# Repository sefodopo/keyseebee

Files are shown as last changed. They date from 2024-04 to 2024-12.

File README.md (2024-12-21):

# KeySeeBee (modified from [TeXitoi/keyseebee](https://github.com/TeXitoi/keyseebee))

KeySeeBee

KeySeeBee is a split ergo keyboard. It is only 2 PCB (so the name)
with (almost) only SMD components on it. It's no longer only a keyboard,
it now has keys, USB, rotary encoders, and OLEDs.

The old firmware at [Keyberon](https://github.com/TeXitoi/keyberon), a
pure rust firmware, has not been ported yet as I wanted more of the functionality
that QMK provides without having to code some of those advanced features.

QMK firmware for this version is located [here](https://github.com/sefodopo/qmk_firmware/tree/keyseebee).

## Features

 * 44 keys, using Cherry MX or Kailh choc switches, only 1U keycaps.
 * USB-C connector on the 2 sides.
 * TRRS cable for connecting the 2 halves (for power and UART communication between the 2 halves).
 * 2 STM32F072 MCU, with hardware USB DFU bootloader and crystal less USB;
 * Only onboard SMD components (except for the switches, TRRS
   connector, and optional components).
 * 2 SPI OLED 128x32 3.3V (optional not SMD)
 * 2 EC11 Rotary Encoder (optional not SMD)
 * [Plate files](cad/) (optional).

## Inspiration

 * [Plaid](https://github.com/hsgw/plaid) for "show the components"
 * [GergoPlex](https://www.gboards.ca/product/gergoplex) for "just a keyboard" and "only a PCB with SMD components"
 * [Lily58](https://github.com/kata0510/Lily58) for the thumb cluster
 * [Kyria](https://blog.splitkb.com/blog/introducing-the-kyria) for
   "don't be affraid of pinky stagger"
 * [keyseebee](https://github.com/TeXitoi/keyberon) for initial design without the OLEDs and Encoders and way too many diodes :)

## Gallery

### v0.1, build by TeXitoi

From above with one side upside down

Side view

### v0.1, build by TeXitoi, Gateron silent clear (MX footprint), 3D printed plate

From above

### v0.2, build by eropleco, with 1.2mm anodized aluminium plate

Left

Right

### v0.3, build by TeXitoi, Gateron silent clear, 3D printed fat plate

Side view

### v0.4, build by Sefodopo, Coming Sometime?

## Bill Of Materials

Price is for 5 keyboards including shipping.

|Item |Package|Qty|Remarks |Price |
|---|---|--:|---|-----:|
|[Left PCB](pcb/gerbers/) | |  1|Ordered at [JLCPCB](https://jlcpcb.com)| |
|[Right PCB](pcb/gerbers/) | |  1|Ordered at [JLCPCB](https://jlcpcb.com)|33.14€|
|[USB-C connector](https://www.aliexpress.com/item/33004501788.html) |16 pins|  2| | 1.44€|
|[PJ320A TRRS connector](https://www.aliexpress.com/item/4000661212458.html)| |  2| | 1.01€|
|[STM32F072CBT6 MCU](https://www.aliexpress.com/item/1005002841528809.html)|LQFP-48|  2|STM32F072C8T6 would also work | 9.65€|
|[XC6206P332MR regulator](https://www.aliexpress.com/item/33015891307.html)|SOT-23 |  2|Price is for 50 | 1.93€|
|[SMD switch](https://www.aliexpress.com/item/4000546059630.html) | 3×6mm |  4|Price is for 100 | 1.35€|
|[5.1kΩ resistor](https://www.aliexpress.com/item/32865947306.html) | 0805  |  6|Price is for 100 | |
|[1µF capacitor](https://www.aliexpress.com/item/32964553793.html) | 0805  |  4|Price is for 100 | |
|[100nF capacitor](https://www.aliexpress.com/item/32964553793.html) | 0805  | 10|Price is for 100 | 3.46€|
|[Bumpers](https://www.aliexpress.com/item/32289191938.html) | 5×2mm | 10|Price is for 100 | 1.75€|
|[Cherry MX compatible](https://www.aliexpress.com/item/32836368723.html) or [Kailh Choc](https://www.aliexpress.com/item/1005005883472162.html) switch|5 pins (PCB mount)|44| | |
|1U keycap compatible with the chosen switches | | 44| | |
|[TRRS cable](https://www.aliexpress.com/item/1005003677396291.html) |Jack 3.5mm| 1|4 contacts needed | |
|[USB-C cable](https://www.aliexpress.com/item/1005002811739151.html) | |  1|USB-2 is enough | |

About 60€ without switches, keycaps and cables for 5 keyboards
(12€/keyboard).

## Compiling and flashing

Follow the QMK guides using my branch of qmk_firmware (or copy my code, idk)... I might add more specific steps in the future.
## What's the layout

Yeah, I'm still figuring it out. I really prefer ZMK and if I can get ZMK working on this keyboard, I'll start using that instead
and update the layout here for what I like.

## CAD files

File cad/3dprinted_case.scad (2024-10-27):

use <functions.scad>

// Change to large number when pruducing end result
// 256 seems fine for production...
$fn = $preview ? 16 : 256;


// Screws and Encoders are different on each side
is_right = false;
// Select the part to show, b bottom, t top, p plate
part = "a";

// See functions.scad for more info
switch_hole = 14;
plate_thickness = 5;
switch_snapping = 1.5;
plate_case_tolerance = 0.03;
plate_inset = 1;
keycap_length = 18.3;
keycap_tolerance = 0.5;
// PCB is 4.3
screw_hole_diameter = 3; 
screw_depth = plate_thickness - switch_snapping-0.2;
chamfer_depth = 0.2;
rim_height = 6;
// Make sure to check dovetails when adjusting
case_width = 3;
case_pcb_tolerance = 0.3;
pcb_thickness = 1.6;
bottom_thickness = 2;
// Below the pcb, pcb+components on back (1.6+2ish)=4ish
case_separation = 4;
case_depth = case_separation+bottom_thickness;
// Depth of screw head for countersink I measured 1.2. Higher number to require shorter screws
screw_head = 3;
// 2.1 shrunk down to 2 and 2.3 was still just barely tight
screw_outer_diameter = 2.4;
// 4 shrunk too much for my wider head screws
screw_head_diameter = 4.5;
usb_thickness = 8;
corner_radius = 3;
bottom_case_tolerance = plate_case_tolerance;

tenting_angle = 25;

module everything() {
  if (part == "b") {
    bottom();
    tent();
  } else if (part == "t")
    rims();
  else if (part == "p")
    real_plate();
  else {
    tent();
    bottom();
    rims();
    real_plate();
  }
}

module tent() {
  angle = tenting_angle;
  outer_width = 136.165+2*(case_width+case_pcb_tolerance);
  right_offset = 85.835+case_width+case_pcb_tolerance;
  left_offset = 50.44+case_width+case_pcb_tolerance;
  start = plate_thickness+case_depth;
  cylen = outer_width * tan(angle)+0.02;
  cydia = 5;
  if (angle >= 5) translate([0,0,start-0.1-0.001]) difference() {
    linear_extrude(outer_width*tan(angle)+1) rim_outline();
    translate([-0.001,-0.001,-0.001+right_offset*tan(angle)+1]) rotate([0,angle,0]) linear_extrude(outer_width*tan(angle)+1+0.002) offset(delta=outer_width/cos(angle)-outer_width) rim_outline();
    if (outer_width*tan(angle)+1 > 10) {
      hyp = tan(angle)*outer_width-10;
      #translate([-left_offset-0.001,-75,10]) rotate([0,angle-90,0]) cube([hyp*cos(angle)+1.002,150,sin(angle)*hyp+1.001]);
    }
    translate([0,0,-0.001]) plate_screw_placement() {
      cylinder(h=1,d1=screw_head_diameter, d2=cydia);
      translate([0,0,1-0.001]) cylinder(h=cylen-1,d=cydia);
    }
  }
}

scale([is_right?-1:1,1,1]) everything();


// Top level modules
module real_plate() {
  difference() {
    linear_extrude(plate_thickness-0.48) difference() {
      offset(delta=plate_inset) plate_outline_interconnect();
      weird_rim_cutout();
    }
    translate([0,0,-0.001]) linear_extrude(plate_thickness+0.002) key_holes();
    translate([0,0,switch_snapping]) linear_extrude(plate_thickness+0.001) key_holes(15);
    translate([0,0,plate_thickness-screw_depth]) plate_screw_placement() {
      cylinder(h=screw_depth+0.001, d=screw_hole_diameter);
    };
    smd_holes();
    encoder_hole();
    usb_holes();
  }
}

module rims() {
  module case_rims() {
    difference() {
        fill() rim_placement();
        offset(delta=-case_width) fill() rim_placement();
      }
  }
  // We go from top to bottom which is actually bottom to top since the model is flipped :)
  difference() {
    union() {
      // top rounded part of case
      translate([0,0,-rim_height]) difference() {
        rd = 0.2;
        radius = case_width+case_pcb_tolerance-rd;
        minkowski() {
          linear_extrude(height=rim_height-radius+0.001) offset(delta=rd) pcb_outline();
          translate([0,0,radius]){
            difference() { // semisphere
              sphere(r=radius);
              translate([0,0,radius+0.001]) cube(radius*2+0.002, center=true);
            }
          }
        }
        translate([0,0,-0.001]) linear_extrude(height=rim_height+0.003)plate_outline();
      }

      // plate slice
      translate([0,0,-0.001]) linear_extrude(plate_thickness-0.4+0.002) {
        difference() {
          rim_placement(); 
          offset(delta=plate_inset+plate_case_tolerance) plate_outline_interconnect();
        }
        offset(delta=-2*plate_case_tolerance) weird_rim_cutout();
      }
      translate([0,0,plate_thickness-0.4-0.001]) linear_extrude(0.4+0.002) difference() {
        fill() rim_placement();
        plate_outline();
      }

      // pcb slice
      translate([0,0,plate_thickness-0.001]) linear_extrude(case_depth-bottom_thickness+0.002) difference() {
        rim_outline();
        offset(delta=-case_width) rim_outline();
      }

      // bottom cover slice
      translate([0,0,plate_thickness+case_depth-bottom_thickness-0.001]) linear_extrude(height=bottom_thickness+0.002) difference() {
        rim_outline();
        offset(r=-case_width/2) rim_outline();
      }
    }
    encoder_hole();
    smd_holes();
    translate([0,0,switch_snapping]) linear_extrude(plate_thickness+0.001) key_holes(15);
    translate([0,0,plate_thickness-screw_depth]) plate_screw_placement() {
      cylinder(h=screw_depth+0.002, d=screw_hole_diameter);
    };
    usb_holes();
    // trrs port
    translate([-46.863,19.652,plate_thickness-6]) linear_extrude(6) square([7,15], center=true);
    translate([-46.863,26,plate_thickness-2.5]) rotate(-90, [1,0,0]) linear_extrude(20) circle(d=8);
  }
}


module bottom() {
  start = plate_thickness+case_depth-bottom_thickness;
  end = plate_thickness+case_depth;
  difference() {
    union() {
      translate([0,0,start]) linear_extrude(bottom_thickness) 
        offset(r=-case_width/2) offset(delta=-bottom_case_tolerance) rim_outline();
      plate_screw_placement() {
        translate([0,0,plate_thickness+bottom_case_tolerance]) cylinder(h=2+0.001,d=4);
        translate([0,0,plate_thickness+bottom_case_tolerance+1.8-0.001]) cylinder(h=start-plate_thickness-bottom_case_tolerance+0.001, d1=4, d2=10);
      }
    }

    plate_screw_placement() {
      translate([0,0,start-case_separation-0.001]) cylinder(h=bottom_thickness+case_separation+0.002,d=screw_outer_diameter);
      translate([0,0,end-screw_head]) cylinder(h=1.5+0.001, d1=screw_outer_diameter, d2=screw_head_diameter);
      translate([0,0,end-screw_head+1.5-0.001]) cylinder(h=screw_head-1.5+0.002,d=screw_head_diameter);
    }
  }
}


// Top level 2d modules

// The outline of the plate where the rims should start
module plate_outline() {
  // My keycaps are 18.3mm^2
  offset(delta=keycap_tolerance) key_holes(keycap_length);
}

module weird_rim_cutout() {
  offset(delta=plate_case_tolerance) intersection() {
    rim_placement();
    translate([-10,-37.965]) square([40,20]);
  }
}

module plate_outline_interconnect() {
  plate_outline();

  // Add padding for the screw
  translate([-27,-49]) square([10,10]);

  // Dovetails
  d = keycap_length/2+keycap_tolerance+plate_inset;
  translate([76.2+d-0.001,-12.7]) rotate(-90) dovetail(w=20,h=0.3);
  translate([-19.05-d+0.001,0]) rotate(90) dovetail(w=17,h=1);
  translate([57.15-6,-29.21-d+0.001]) rotate(180) dovetail(w=8,h=2);
  translate([57.15+2,8.89+d-0.001]) dovetail(w=4,h=2);
  translate([-32.131,-45.72]) rotate(26.5) translate([0,-d+0.001]) rotate(180) dovetail(w=7,h=0.5);
  translate([19.05,21.59+d-0.001]) dovetail(h=0.01);
  translate([-2,19.05+d-0.001]) dovetail(w=7, h=0.3);
  translate([15,-38.1-d+0.001]) rotate(180) dovetail(w=10,h=0.5);
}

module dovetail(w=10,h=2) {
  polygon([[-w/2,0], [-w/2-h,h], [w/2+h,h], [w/2,0]]);
}

module pcb_outline() {
    union() {
        outline();
        if (is_right)
            polygon([[-36.394,-58.461], [-50.165,-31.115],[-50.165,26.035],[-28.575,26.035],[0.025,-50.140]]);
        else
            polygon([[-36.322,-58.42],[-50.165,-31.115],[-50,26],[-28.5,26],[0,-50]]);
    }
}

module rim_outline() {
  offset(r=case_width+case_pcb_tolerance) pcb_outline();
}

module rim_placement() {
    difference(){
        rim_outline();
        plate_outline();
    }
}

module encoder_placement() {
    translate(is_right?[-39,-26.5]:[-39.5,-25.5]) children();
}

module plate_screw_placement() {
    if (is_right) {
        translate([-9.135,9.065]) children();
        translate([-21.035,-42.035]) children();
        translate([66.465,-0.735]) children();
        translate([67.265,-22.135]) children();
    } else {
        translate([-9.3,9.1]) children();
        translate([-21.2,-42]) children();
        translate([67.1,-22.1]) children();
        translate([66.3,-0.7]) children();
    }
}

module key_holes(size=switch_hole) {
    key_placement() square(size, center=true);
}


// 3d holes

module smd_holes() {
  // smd components
  translate([-28.165-22,-18.965,plate_thickness-3-0.001]) linear_extrude(3+0.003) square([22,45], center=false);
}
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

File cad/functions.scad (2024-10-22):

// You can change the parameters in the header in openscad, then
// render, and then export in the format you need.
//
// You can also include this file in your own scad file, and use the
// modules to create your own case:
//  - outline module (2D outline of the plate),
//  - plate module (2D draw of the plate, with switch holes),
//  - key_placement module (2D placement of the keys centered, to be
//    used with children) to create your own case.

switch_hole=13.9;// by spec should be 14, can be adjusted for printer imprecision

// Code here, not to be modified if you want keyseebee compatibility
inter_switch=19.05;
d=2.54;
delta=[-d,0,d,0,-4*d,-5*d];// column stagger

// this is a bug in v0.1 and v0.2, not needed after
right_thumb_offset=0.635;
function thumb_offset(is_right) = (is_right?1:0)*right_thumb_offset;

module key_placement_without_extreme(is_right=false) {
     for (i=[0:5]) for (j=[0:2]) translate([(i-1)*inter_switch, -(j-1)*inter_switch+delta[i]]) children();
     for (i=[0:2]) translate([(i-0.5)*inter_switch+thumb_offset(is_right), -2*inter_switch+min(delta[i], delta[i+1])]) children();
}

module extreme_key_placement(is_right=false) {
     translate([-32.131+thumb_offset(is_right), -45.720]) rotate(26.5) children();
}

module key_placement(is_right=false) {
     key_placement_without_extreme(is_right) children();
     extreme_key_placement(is_right) children();
}

module outline(is_right=false) {
     union() {
          hull() key_placement_without_extreme(is_right) square(inter_switch, center=true);
          translate([-inter_switch, -2*inter_switch+delta[0]]) square(inter_switch, center=true);
          hull() {
               extreme_key_placement(is_right) square(inter_switch, center=true);
               translate([-0.5*inter_switch+thumb_offset(is_right), -2*inter_switch+delta[0]]) square(inter_switch, center=true);
          }
     }
}

module plate(is_right=false) {
     difference() {
          outline(is_right);
          key_placement(is_right) square([switch_hole, switch_hole], center=true);
     }
}

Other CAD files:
cad/top_mx_plate.printing.scad

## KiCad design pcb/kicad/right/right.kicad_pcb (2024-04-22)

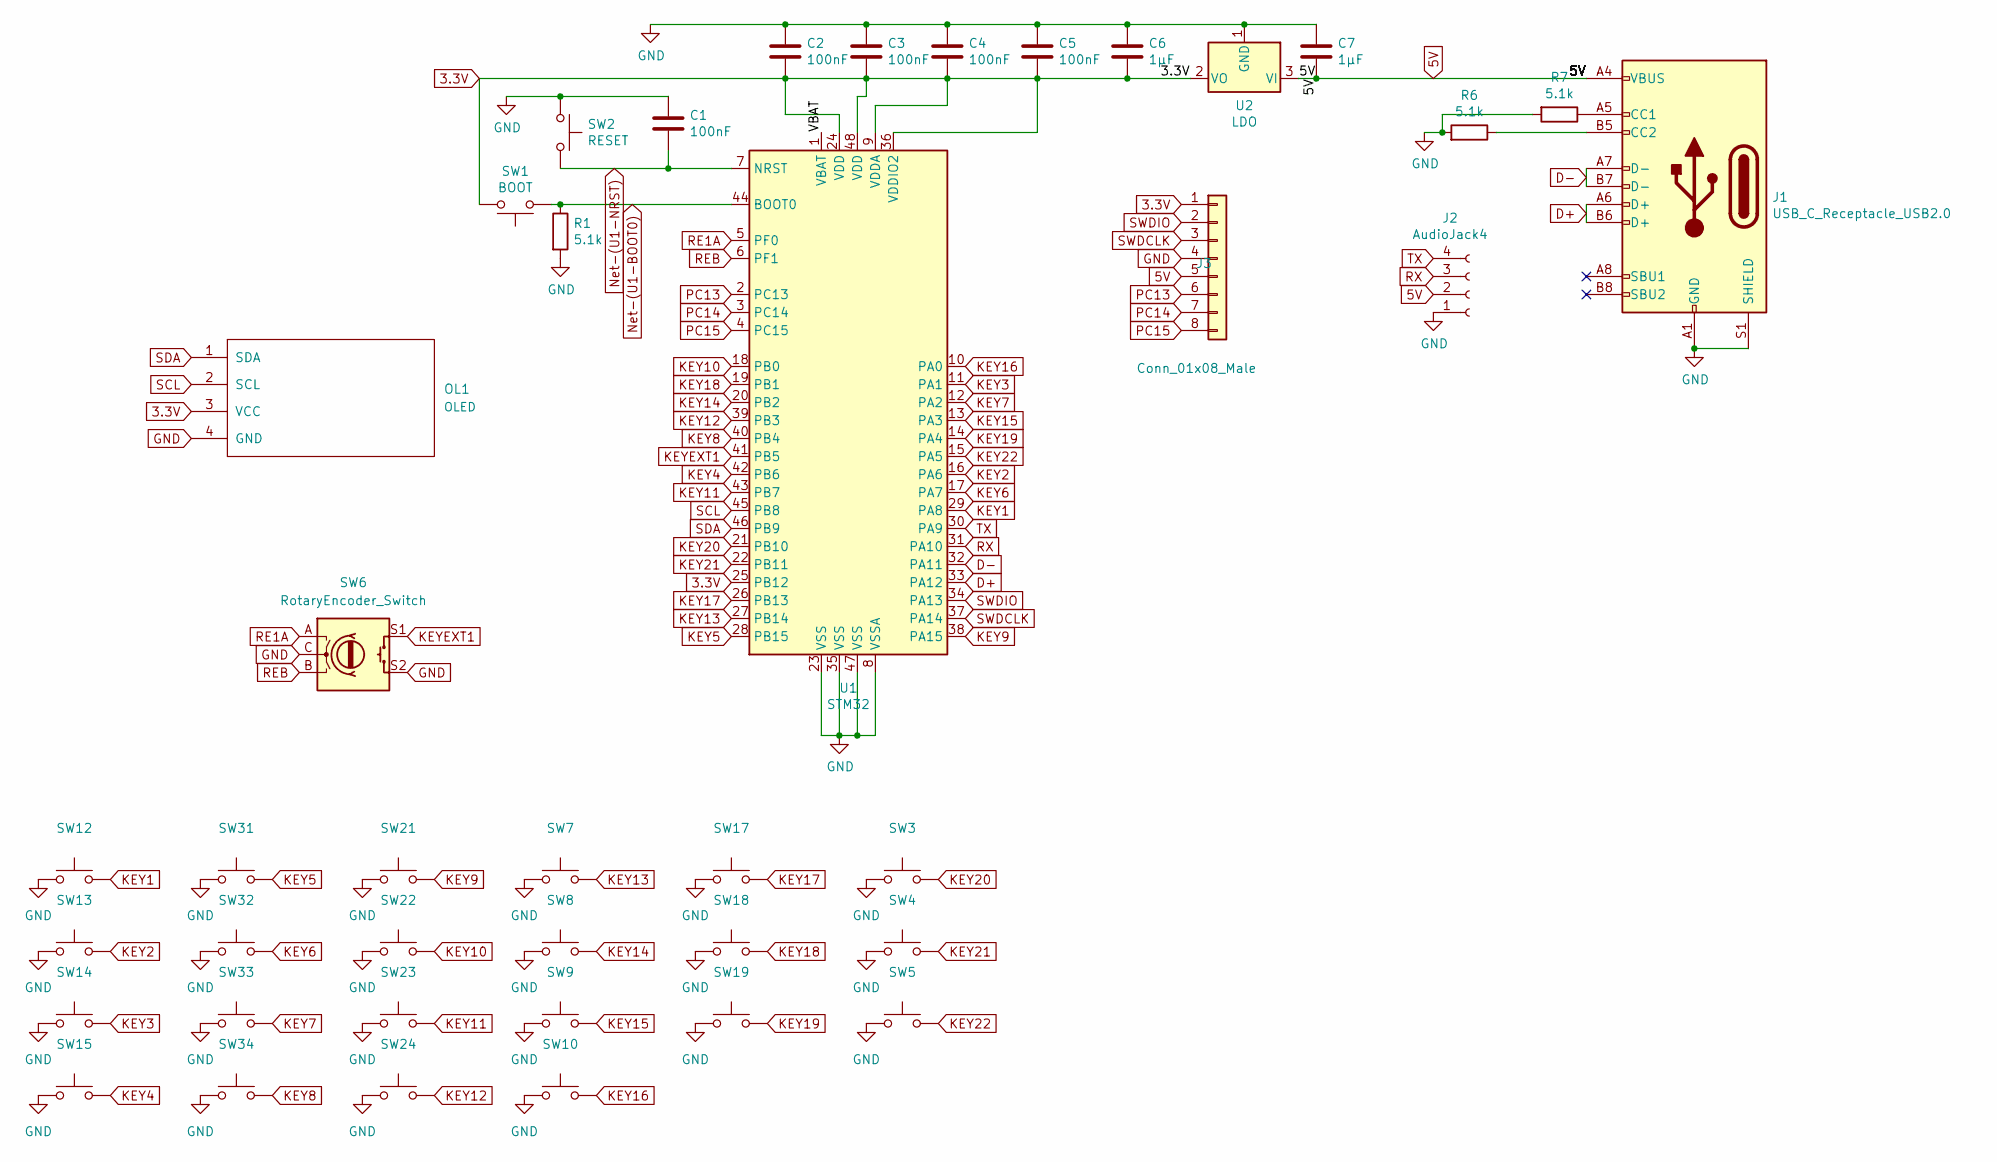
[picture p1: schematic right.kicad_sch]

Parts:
C1, C2, C3, C4, C5: 100nF; C_0805_2012Metric_Pad1.15x1.40mm_HandSolder
C6, C7: 1µF; C_0805_2012Metric_Pad1.15x1.40mm_HandSolder
J1: USB_C_Receptacle_USB2.0; USB_C_Receptacle_HRO_TYPE-C-31-M-12
J2: AudioJack4; TRRS-PJ-320A-no-Fmask
J3: Conn_01x08_Male; Harwin_M20-89008xx_1x08_P2.54mm_Horizontal
OL1: OLED; OLED_1side
R1, R6, R7: 5.1k; R_0805_2012Metric_Pad1.15x1.40mm_HandSolder
SW1: BOOT; SW_SPST_CK_RS282G05A3
SW2: RESET; SW_SPST_CK_RS282G05A3
SW3, SW4, SW5, SW7, SW8, SW9, SW10, SW12, SW13, SW14, SW15, SW17, SW18, SW19, SW21, SW22, SW23, SW24, SW31, SW32, SW33, SW34: SW_Push; CherryMX_Choc_MXHotswap_1u
SW6: RotaryEncoder_Switch; RotaryEncoder_Alps_EC11E-Switch_Vertical_H20mm
U1: STM32; LQFP-48_7x7mm_P0.5mm
U2: LDO; SOT-23

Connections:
3.3V: C2.2, C3.2, C4.2, C5.2, C6.2, J3.1, OL1.3 (VCC), SW1.2, U1.9 (VDDA), U1.24 (VDD), U1.25 (PB12), U1.36 (VDDIO2), U1.48 (VDD), U2.2 (VO)
5V: C7.2, J1.A4 (VBUS), J1.A9 (VBUS), J1.B4 (VBUS), J1.B9 (VBUS), J2.2, J3.5, U2.3 (VI)
/VBAT: U1.1 (VBAT)
D+: J1.A6 (D+), J1.B6 (D+), U1.33 (PA12)
D-: J1.A7 (D-), J1.B7 (D-), U1.32 (PA11)
GND: C1.1, C2.1, C3.1, C4.1, C5.1, C6.1, C7.1, J1.A1 (GND), J1.A12 (GND), J1.B1 (GND), J1.B12 (GND), J1.S1 (SHIELD), J2.1, J3.4, OL1.4 (GND), R1.2, R6.2, R7.2, SW2.1, SW3.2, SW4.2, SW5.2, SW6.C, SW6.S2, SW7.2, SW8.2, SW9.2, SW10.2, SW12.2, SW13.2, SW14.2, SW15.2, SW17.2, SW18.2, SW19.2, SW21.2, SW22.2, SW23.2, SW24.2, SW31.2, SW32.2, SW33.2, SW34.2, U1.8 (VSSA), U1.23 (VSS), U1.35 (VSS), U1.47 (VSS), U2.1 (GND)
KEY1: SW12.1, U1.29 (PA8)
KEY2: SW13.1, U1.16 (PA6)
KEY3: SW14.1, U1.11 (PA1)
KEY4: SW15.1, U1.42 (PB6)
KEY5: SW31.1, U1.28 (PB15)
KEY6: SW32.1, U1.17 (PA7)
KEY7: SW33.1, U1.12 (PA2)
KEY8: SW34.1, U1.40 (PB4)
KEY9: SW21.1, U1.38 (PA15)
KEY10: SW22.1, U1.18 (PB0)
KEY11: SW23.1, U1.43 (PB7)
KEY12: SW24.1, U1.39 (PB3)
KEY13: SW7.1, U1.27 (PB14)
KEY14: SW8.1, U1.20 (PB2)
KEY15: SW9.1, U1.13 (PA3)
KEY16: SW10.1, U1.10 (PA0)
KEY17: SW17.1, U1.26 (PB13)
KEY18: SW18.1, U1.19 (PB1)
KEY19: SW19.1, U1.14 (PA4)
KEY20: SW3.1, U1.21 (PB10)
KEY21: SW4.1, U1.22 (PB11)
KEY22: SW5.1, U1.15 (PA5)
KEYEXT1: SW6.S1, U1.41 (PB5)
unnamed: J1.A5 (CC1), R7.1
unnamed: J1.B5 (CC2), R6.1
unnamed: R1.1, SW1.1, U1.44 (BOOT0)
unnamed: C1.2, SW2.2, U1.7 (NRST)
PC13: J3.6, U1.2 (PC13)
PC14: J3.7, U1.3 (PC14)
PC15: J3.8, U1.4 (PC15)
RE1A: SW6.A, U1.5 (PF0)
REB: SW6.B, U1.6 (PF1)
RX: J2.3, U1.31 (PA10)
SCL: OL1.2 (SCL), U1.45 (PB8)
SDA: OL1.1 (SDA), U1.46 (PB9)
SWDCLK: J3.3, U1.37 (PA14)
SWDIO: J3.2, U1.34 (PA13)
TX: J2.4, U1.30 (PA9)

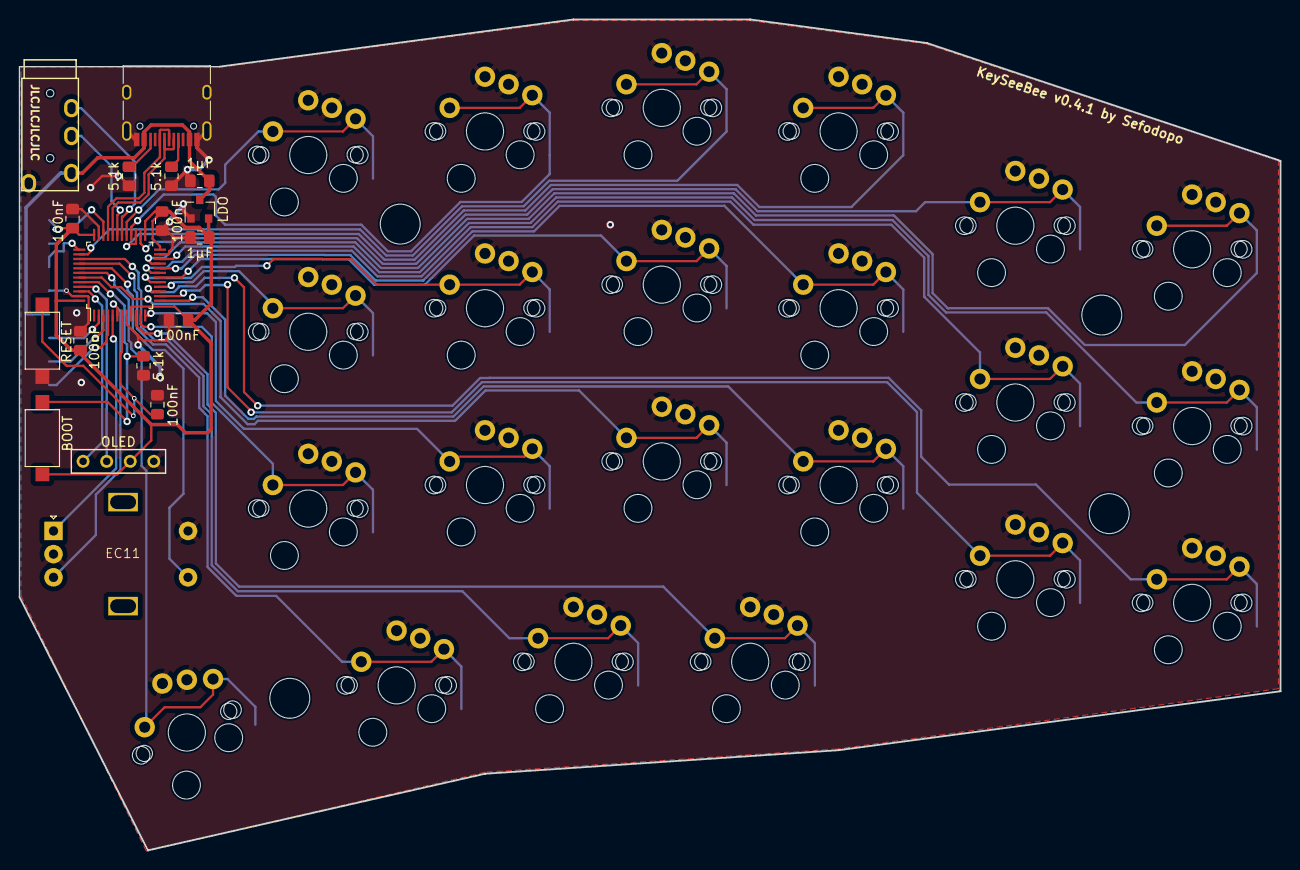
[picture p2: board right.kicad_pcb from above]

Board: 2 copper layers, 135.9 x 89.5 mm, 41 parts (1 on the bottom side), 43 nets.

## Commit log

2024-04-22 Updated to v0.4.1 with direct wired switches and Rotary Encoders and OLEDS added along with pcb plates
    Be warned that the keyplate is missing a cutout for the rotary encoder
    and OLED module
    [left.kicad_pcb, left.kicad_sch, leftkeyplate.kicad_pcb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]
2024-10-18 Working on top plate
    [top_mx_plate.printing.scad]
2024-10-18 Working on compromise
    [top_mx_plate.printing.scad]
2024-10-20 Maybe we don't compromise?
    [top_mx_plate.printing.scad]
2024-10-21 Think the plate is ready for printing
    [top_mx_plate.printing.scad]
2024-10-21 Cleaned up a bit, started to make adjustments for future
    [top_mx_plate.printing.scad]
2024-10-21 Added bottom case
    [top_mx_plate.printing.scad]
2024-10-21 Fixed formatting
    [top_mx_plate.printing.scad]
2024-10-21 Fixed tolerances
    [top_mx_plate.printing.scad]
2024-10-21 Added dovetails
    [top_mx_plate.printing.scad]
2024-10-21 Added chamfers
    [functions.scad, top_mx_plate.printing.scad]
2024-10-21 Right side testing with no tent
    [top_mx_plate.printing.scad]
2024-10-21 Fixed dovetails for right side test
    [top_mx_plate.printing.scad]
2024-10-21 Right version 1.2 Adjusted tolerances and bottom plate
    [top_mx_plate.printing.scad]
2024-10-22 Left version 1.3 More adjustments...h
    [top_mx_plate.printing.scad]
2024-10-22 Fixed overlap causing plate not to insert into top
    [3dprinted_case.scad]
2024-10-22 Added more dovetails and adjusted screw hole size to work with m2 heat inserts
    [3dprinted_case.scad]
2024-10-22 Rounded the top edge instead of a chamfer
    [3dprinted_case.scad, functions.scad]
2024-10-23 Right version 1.4, hopefully last version unless I like the chamfer better than the bevel
    [3dprinted_case.scad]
2024-10-26 Left version 1.5
    [3dprinted_case.scad]
2024-10-27 Added tenting
    [3dprinted_case.scad]
